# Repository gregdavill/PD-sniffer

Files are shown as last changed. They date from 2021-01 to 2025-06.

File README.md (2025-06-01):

# PD-Sniffer

This project is based off the Twinkie, a Google designed PD sniffer/analyser. [link](https://www.chromium.org/chromium-os/developer-library/guides/hardware-schematics/twinkie/)

Unfortunately the original designers of the Twinkie designed the hardware with laptop like specifications. As a result the design features a 6L PCB with stacked micro-vias. This makes it expensive to manufacture.

This re-design aims to keep the board specifications within the scope of PCB prototyping services, so it is easier for hobbyists and other open-source contributors to create and build a unit.

## Hardware versions

### v0.1 (FreshTwinkie)
The initial version aims to remain pin compatible with the original design, so firmware can be re-used. The main MCU is swapped from a BGA package to a QFN, and a 4L board construction is used. As a result many BGA devices are still used, as these were un-changed from the original design.

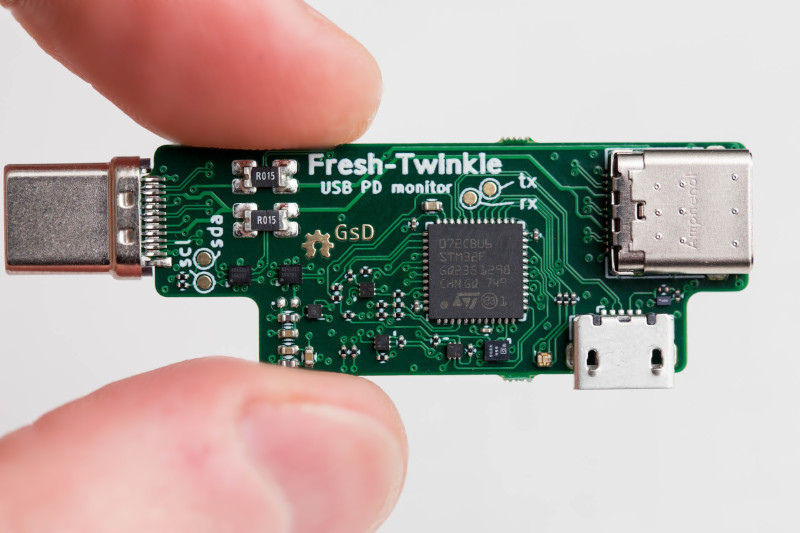
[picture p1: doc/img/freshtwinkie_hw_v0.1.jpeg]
fresh-twinkie-hw-v0.1


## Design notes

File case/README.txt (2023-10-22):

Parts list:
- 1x lower-case.stl
- 1x upper-case.stl
- 2x M2x8mm screw
- 2x M2 nut

This case has very fine features, mainly the latch, and works best when printed in plastics like PETG.
It was validated in transparent SUNLU PETG using a 0.4mm nozzle, sliced with variable layer height
(adaptive, factor 0.5) and 50% infill with PrusaSlicer 2.5.2. The LED shines brightly through the case
so no aperture for the LED was added.

SolveSpace exports triangle meshes that are a little broken, and the STL files included were repaired
through the Netfabb service.

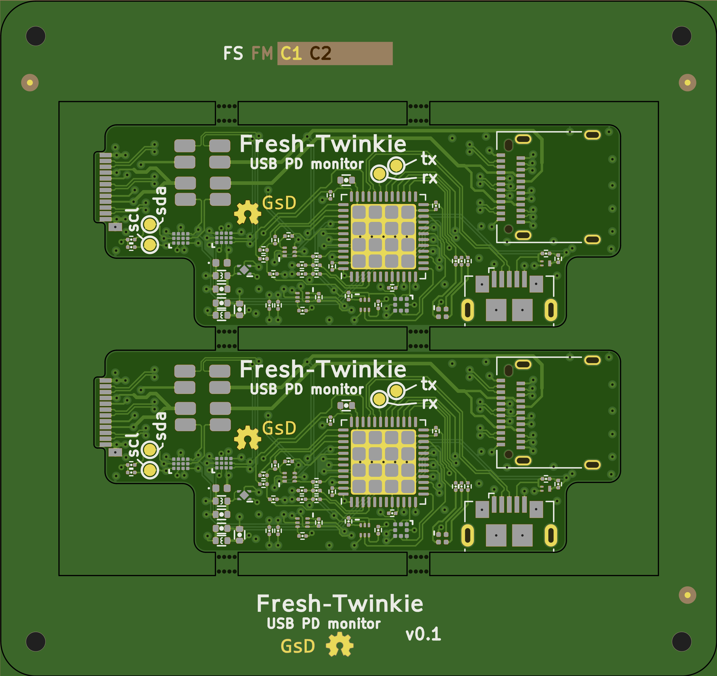
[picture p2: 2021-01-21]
hw/FreshTwinkie_v0.1_panel/plot/FreshTwinkie_v0.1_panel-Front.png

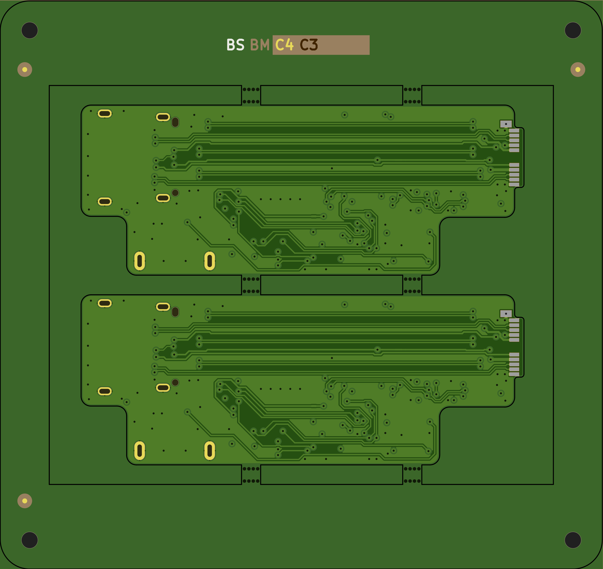
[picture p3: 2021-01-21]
hw/FreshTwinkie_v0.1_panel/plot/FreshTwinkie_v0.1_panel-Back.png

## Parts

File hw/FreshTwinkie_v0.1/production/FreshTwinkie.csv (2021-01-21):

Source: | /home/greg/projects/FreshTwinkie/hardware/FreshTwinkie_v0.1/FreshTwinkie.sch
Date: | Mon 05 Aug 2019 21:20:34 ACST
Tool: | Eeschema 5.1.2-f72e74a~84~ubuntu18.04.1
Generator: | /usr/share/kicad/plugins/bom_csv_grouped_by_value.py
Component Count: | 50
Individual Components:
Item | Qty | Reference(s) | Value | LibPart | Footprint | Datasheet | Mfg | PN
 |  | C1 | 1uF | Device:C | pkl_dipol:C_0402 | ~ | Samsung Electro-Mechanics | CL05A105MQ5NNNC
 |  | C2 | 100nF | Device:C | pkl_dipol:C_0201 | ~ | Samsung Electro-Mechanics | CL03A104KQ3NNNC
 |  | C3 | 100nF | Device:C | pkl_dipol:C_0201 | ~ | Samsung Electro-Mechanics | CL03A104KQ3NNNC
 |  | C4 | 4.7uF | Device:C | pkl_dipol:C_0402 | ~ | Samsung Electro-Mechanics | CL05A475MQ5NRNC
 |  | C5 | 10nF | Device:C | pkl_dipol:C_0201 | ~ | Samsung Electro-Mechanics | CL03B103KP3NNNC
 |  | C6 | 1uF | Device:C | pkl_dipol:C_0402 | ~ | Samsung Electro-Mechanics | CL05A105MQ5NNNC
 |  | C7 | 4.7uF | Device:C | pkl_dipol:C_0402 | ~ | Samsung Electro-Mechanics | CL05A475MQ5NRNC
 |  | C8 | 100nF | Device:C | pkl_dipol:C_0201 | ~ | Samsung Electro-Mechanics | CL03A104KQ3NNNC
 |  | D1 | 5.6V | Device:D_Zener_ALT | Diode_SMD:D_0402_1005Metric | ~
 |  | D2 | LED_ARGB | Device:LED_ARGB | gkl_led:0404LED_RGB | ~
 |  | FB1 | 600R | Device:Ferrite_Bead_Small | pkl_dipol:L_0402 | ~ | Murata Electronics North America | BLM15AG601SN1D
 |  | FB2 | 600R | Device:Ferrite_Bead_Small | pkl_dipol:L_0402 | ~ | Murata Electronics North America | BLM15AG601SN1D
 |  | J1 | USB_B_Micro | Connector:USB_B_Micro | Connector_USB:USB_Micro-B_GCT_USB3076-30-A | ~ | GCT | USB3076-30-A
 |  | J2 | USB_C_Receptacle | Connector:USB_C_Receptacle | Connector_USB:USB_C_Receptacle_Amphenol_12401610E4-2A | https://www.usb.org/sites/default/files/documents/usb_type-c.zip | Amphenol ICC (Commercial Products) | 12401610E4#2A
 |  | NT1 | Net-Tie_2 | Device:Net-Tie_2 | NetTie:NetTie-2_SMD_Pad0.5mm | ~
 |  | P1 | USB_C_Plug | Connector:USB_C_Plug | Connector_USB:USB_C_Plug_Molex_105444 | https://www.usb.org/sites/default/files/documents/usb_type-c.zip | Wurth Electronics Inc. | 632712000021
 |  | Q1 | PMDXB600UNE | gkl_mosfet:PMDXB600UNE | gkl_housings_qfn:DFN1010B-6 (SOT1216) | https://assets.nexperia.com/documents/data-sheet/PMDXB600UNE.pdf | Nexperia USA Inc. | PMDXB600UNEZ
 |  | Q2 | PMDXB600UNE | gkl_mosfet:PMDXB600UNE | gkl_housings_qfn:DFN1010B-6 (SOT1216) | https://assets.nexperia.com/documents/data-sheet/PMDXB600UNE.pdf | Nexperia USA Inc. | PMDXB600UNEZ
 |  | Q3 | PMDXB600UNE | gkl_mosfet:PMDXB600UNE | gkl_housings_qfn:DFN1010B-6 (SOT1216) | https://assets.nexperia.com/documents/data-sheet/PMDXB600UNE.pdf | Nexperia USA Inc. | PMDXB600UNEZ
 |  | Q4 | Q_NMOS_DGS | Device:Q_NMOS_DGS | gkl_housings_qfn:MOSFET_1.0x0.6mm | ~ | Texas Instruments | CSD13381F4
 |  | R1 | 0.015 | gkl_misc:4W_R | gkl_dipol:4W_R_1206 |  | Vishay Dale | WSK1206R0150FEA18
 |  | R2 | 0.015 | gkl_misc:4W_R | gkl_dipol:4W_R_1206 |  | Vishay Dale | WSK1206R0150FEA18
 |  | R3 | 381K | Device:R | gkl_dipol:R_0201 | ~ | Yageo | RC0201FR-07383KL
 |  | R4 | 381K | Device:R | gkl_dipol:R_0201 | ~ | Yageo | RC0201FR-07383KL
 |  | R5 | 4.75K | Device:R | gkl_dipol:R_0201 | ~ | Yageo | RC0201FR-074K75L
 |  | R6 | 4.75K | Device:R | gkl_dipol:R_0201 | ~ | Yageo | RC0201FR-074K75L
 |  | R7 | 1K | Device:R | gkl_dipol:R_0201 | ~ | Yageo | RC0201FR-071KL
 |  | R8 | 1K | Device:R | gkl_dipol:R_0201 | ~ | Yageo | RC0201FR-071KL
 |  | R9 | 12.1K | Device:R | gkl_dipol:R_0201 | ~ | Yageo | RC0201FR-0712K1L
 |  | R10 | 12.1K | Device:R | gkl_dipol:R_0201 | ~ | Yageo | RC0201FR-0712K1L
 |  | R11 | 5.11K | Device:R | gkl_dipol:R_0201 | ~ | Yageo | RC0201FR-075K11L
 |  | R12 | 5.11K | Device:R | gkl_dipol:R_0201 | ~ | Yageo | RC0201FR-075K11L
 |  | R13 | 35.7K | Device:R | gkl_dipol:R_0201 | ~ | Yageo | RC0201FR-0735K7L
 |  | R14 | 35.7K | Device:R | gkl_dipol:R_0201 | ~ | Yageo | RC0201FR-0735K7L
 |  | R15 | 200R | Device:R | gkl_dipol:R_0201 | ~ | Yageo | RC0201FR-07200RL
 |  | R16 | 100R | Device:R | gkl_dipol:R_0201 | ~ | Yageo | RC0201FR-07100RL
 |  | R17 | 200R | Device:R | gkl_dipol:R_0201 | ~ | Yageo | RC0201FR-07200RL
 |  | R18 | 100R | Device:R | gkl_dipol:R_0201 | ~ | Yageo | RC0201FR-07100RL
 |  | R19 | 51.1K | Device:R | gkl_dipol:R_0201 | ~ | Yageo | RC0201FR-0751k1L
 |  | R20 | 51.1K | Device:R | gkl_dipol:R_0201 | ~ | Yageo | RC0201FR-0751k1L
 |  | R21 | 576R | Device:R | gkl_dipol:R_0201 | ~ | Yageo | RC0201FR-07576RL
 |  | R22 | 2.12K | Device:R | gkl_dipol:R_0201 | ~ | Yageo | RC0201FR-072k1L
 |  | R23 | 604R | Device:R | gkl_dipol:R_0201 | ~ | Yageo | RC0201FR-07604RL
 |  | R24 | 2.12K | Device:R | gkl_dipol:R_0201 | ~ | Yageo | RC0201FR-072k1L
 |  | R25 | 806R | Device:R | gkl_dipol:R_0201 | ~ | Yageo | RC0201FR-07806RL
 |  | U1 | INA231 | gkl_sensor:INA231 | gkl_housings_bga:DSBGA-12_1.56x1.39mm_Layout3x4_P0.4mm |  | Texas Instruments | INA231AIYFFR
 |  | U2 | INA231 | gkl_sensor:INA231 | gkl_housings_bga:DSBGA-12_1.56x1.39mm_Layout3x4_P0.4mm |  | Texas Instruments | INA231AIYFFR
 |  | U3 | NCP167 | gkl_pmic:NCP167 | gkl_housings_son:X2SON_4_1.0x1.0mm | http://www.onsemi.com/pub/Collateral/NCP167-D.PDF | ON Semiconductor | NCP167BMX330TBG
 |  | U4 | AD8606ACB | gkl_misc:AD8606ACB | gkl_housings_bga:WLCSP-8 3X3_0.5 | https://www.analog.com/media/en/technical-documentation/data-sheets/AD8605_8606_8608.pdf | Analog Devices Inc. | AD8606ACBZ-REEL7
 |  | U5 | STM32F072CBUx | MCU_ST_STM32F0:STM32F072CBUx | Package_DFN_QFN:QFN-48-1EP_7x7mm_P0.5mm_EP5.6x5.6mm | http://www.st.com/st-web-ui/static/active/en/resource/technical/document/datasheet/DM00090510.pdf | STMicroelectronics | STM32F072CBU6
Collated Components:
Item | Qty | Reference(s) | Value | LibPart | Footprint | Datasheet | Mfg | PN
1 | 2 | C1, C6 | 1uF | Device:C | pkl_dipol:C_0402 | ~ | Samsung Electro-Mechanics | CL05A105MQ5NNNC
2 | 3 | C2, C3, C8 | 100nF | Device:C | pkl_dipol:C_0201 | ~ | Samsung Electro-Mechanics | CL03A104KQ3NNNC
3 | 2 | C4, C7 | 4.7uF | Device:C | pkl_dipol:C_0402 | ~ | Samsung Electro-Mechanics | CL05A475MQ5NRNC
4 | 1 | C5 | 10nF | Device:C | pkl_dipol:C_0201 | ~ | Samsung Electro-Mechanics | CL03B103KP3NNNC
5 | 1 | D1 | 5.6V | Device:D_Zener_ALT | Diode_SMD:D_0402_1005Metric | ~
6 | 1 | D2 | LED_ARGB | Device:LED_ARGB | gkl_led:0404LED_RGB | ~
7 | 2 | FB1, FB2 | 600R | Device:Ferrite_Bead_Small | pkl_dipol:L_0402 | ~ | Murata Electronics North America | BLM15AG601SN1D
8 | 1 | J1 | USB_B_Micro | Connector:USB_B_Micro | Connector_USB:USB_Micro-B_GCT_USB3076-30-A | ~ | GCT | USB3076-30-A
9 | 1 | J2 | USB_C_Receptacle | Connector:USB_C_Receptacle | Connector_USB:USB_C_Receptacle_Amphenol_12401610E4-2A | https://www.usb.org/sites/default/files/documents/usb_type-c.zip | Amphenol ICC (Commercial Products) | 12401610E4#2A
10 | 1 | NT1 | Net-Tie_2 | Device:Net-Tie_2 | NetTie:NetTie-2_SMD_Pad0.5mm | ~
11 | 1 | P1 | USB_C_Plug | Connector:USB_C_Plug | Connector_USB:USB_C_Plug_Molex_105444 | https://www.usb.org/sites/default/files/documents/usb_type-c.zip | Wurth Electronics Inc. | 632712000021
12 | 3 | Q1, Q2, Q3 | PMDXB600UNE | gkl_mosfet:PMDXB600UNE | gkl_housings_qfn:DFN1010B-6 (SOT1216) | https://assets.nexperia.com/documents/data-sheet/PMDXB600UNE.pdf | Nexperia USA Inc. | PMDXB600UNEZ
13 | 1 | Q4 | Q_NMOS_DGS | Device:Q_NMOS_DGS | gkl_housings_qfn:MOSFET_1.0x0.6mm | ~ | Texas Instruments | CSD13381F4
14 | 2 | R1, R2 | 0.015 | gkl_misc:4W_R | gkl_dipol:4W_R_1206 |  | Vishay Dale | WSK1206R0150FEA18
15 | 2 | R3, R4 | 381K | Device:R | gkl_dipol:R_0201 | ~ | Yageo | RC0201FR-07383KL
16 | 2 | R5, R6 | 4.75K | Device:R | gkl_dipol:R_0201 | ~ | Yageo | RC0201FR-074K75L
17 | 2 | R7, R8 | 1K | Device:R | gkl_dipol:R_0201 | ~ | Yageo | RC0201FR-071KL
18 | 2 | R9, R10 | 12.1K | Device:R | gkl_dipol:R_0201 | ~ | Yageo | RC0201FR-0712K1L
19 | 2 | R11, R12 | 5.11K | Device:R | gkl_dipol:R_0201 | ~ | Yageo | RC0201FR-075K11L
20 | 2 | R13, R14 | 35.7K | Device:R | gkl_dipol:R_0201 | ~ | Yageo | RC0201FR-0735K7L
21 | 2 | R15, R17 | 200R | Device:R | gkl_dipol:R_0201 | ~ | Yageo | RC0201FR-07200RL
22 | 2 | R16, R18 | 100R | Device:R | gkl_dipol:R_0201 | ~ | Yageo | RC0201FR-07100RL
23 | 2 | R19, R20 | 51.1K | Device:R | gkl_dipol:R_0201 | ~ | Yageo | RC0201FR-0751k1L
24 | 1 | R21 | 576R | Device:R | gkl_dipol:R_0201 | ~ | Yageo | RC0201FR-07576RL
25 | 2 | R22, R24 | 2.12K | Device:R | gkl_dipol:R_0201 | ~ | Yageo | RC0201FR-072k1L
26 | 1 | R23 | 604R | Device:R | gkl_dipol:R_0201 | ~ | Yageo | RC0201FR-07604RL
27 | 1 | R25 | 806R | Device:R | gkl_dipol:R_0201 | ~ | Yageo | RC0201FR-07806RL
28 | 2 | U1, U2 | INA231 | gkl_sensor:INA231 | gkl_housings_bga:DSBGA-12_1.56x1.39mm_Layout3x4_P0.4mm |  | Texas Instruments | INA231AIYFFR
29 | 1 | U3 | NCP167 | gkl_pmic:NCP167 | gkl_housings_son:X2SON_4_1.0x1.0mm | http://www.onsemi.com/pub/Collateral/NCP167-D.PDF | ON Semiconductor | NCP167BMX330TBG
30 | 1 | U4 | AD8606ACB | gkl_misc:AD8606ACB | gkl_housings_bga:WLCSP-8 3X3_0.5 | https://www.analog.com/media/en/technical-documentation/data-sheets/AD8605_8606_8608.pdf | Analog Devices Inc. | AD8606ACBZ-REEL7
31 | 1 | U5 | STM32F072CBUx | MCU_ST_STM32F0:STM32F072CBUx | Package_DFN_QFN:QFN-48-1EP_7x7mm_P0.5mm_EP5.6x5.6mm | http://www.st.com/st-web-ui/static/active/en/resource/technical/document/datasheet/DM00090510.pdf | STMicroelectronics | STM32F072CBU6

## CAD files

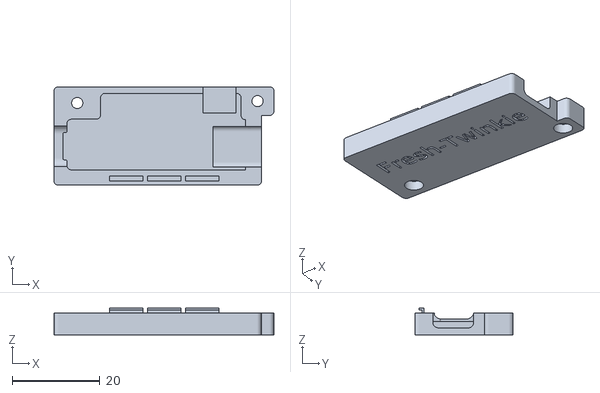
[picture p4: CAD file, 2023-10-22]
case/upper-case.stl
50.1 x 22.5 x 6.09

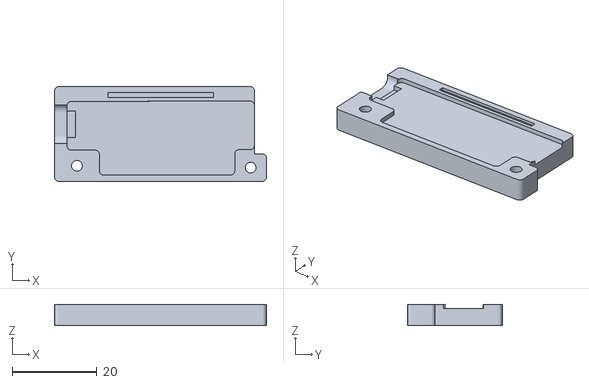
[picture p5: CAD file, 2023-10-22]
case/lower-case.stl
50.1 x 22.4 x 5.00

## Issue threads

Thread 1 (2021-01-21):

[v0.1] ID pin based boot scheme does not work

whitequark, 2021-01-21:
It seems that the USB_B_VBUS net (as shown on original Twinkie schematic) is not connected on Fresh-Twinkie, making it impossible (AFAIK) to boot without cutting the trace. The workaround is to cut the BOOT trace and connect it to Vcc.

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

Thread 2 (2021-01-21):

[v0.1] Simplify bootloader entry

whitequark, 2021-01-21:
The ID pin based bootloader entry scheme is highly inconvenient and requires using an illegal USB cable. Most end users will probably only need to enter the ROM bootloader once, so a test point is fine. I can see developers entering the ROM bootloader more often, so a button in parallel with a test point (which could be DNP) would be quite nice, especially on a high density board like this.

whitequark, 2021-02-09:
> if you are planning to re-use part of the original firmware, it does include a 'dfu' command over the USB-serial console to switch it back to bootloader mode

Yeah and the command is broken...

whitequark, 2021-02-09:
I think the command might actually be broken because of #1? I don't know how exactly it works, but the symptoms are that I can enter DFU mode but trying to flash anything instantly resets the device. I haven't tried it with the workaround for #1 yet.

whitequark, 2021-02-09:
Sorry, I understand I probably sound quite hostile, that's not my intention. I've just had a lot of trouble with both USB PD *and* USB PD debuggers and after a few months of it that gets frustrating.

dnschneid, 2021-02-16:
Buttons are nice as long as you can access them when the unit is enclosed in its enclosure and including it doesn't cause the enclosure to be larger than absolutely necessary (since any increase in case size results in more torque on the Type-C plug).

I think the USB-ID trick is especially convenient for us since we've been using the trick across multiple internal boards for years, so our devs tend to have them on-hand.  Never had an issue with it (although it's best to plug in the micro-B side before the usb-A side).

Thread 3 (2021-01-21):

[v0.1] Use more DIY friendly packages

whitequark, 2021-01-21:
All of the components on the board are available in larger/coarser packages than the v0.1 design. Switching to 0603 min passives and replacing BGA/CSP packages with QFN/DFN would make the board easier to assemble and examine while not making it much larger.

FalconFour, 2024-11-12:
Aye... I wanted to build this but PCBway barfed it back out saying the clearance is too small (minimum 0.1mm, but wider is much cheaper). Board seems to have 0.08mm. Would much prefer a larger board that omits USB/Thunderbolt passthrough, something simple that just lets me intercept USB-PD data, something just in my personal toolkit to help observe the invisible (and sometimes problematic) things that devices do...

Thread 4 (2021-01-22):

RFC: Improving alternate modes for captive cable compatibility.

hardkrash, 2021-01-22:
The design currently has a single routing of USB 2.0 pairs.  This can cause some adapters with alternate modes to fail to operate properly.  Captive plug alternate modes can remap the alternate USB pair B6+B7 for its own purposes.  reference Figure E2 in section e.2.1 of the document [USB Type-C Spec R2.0 - August 2019.pdf](https://usb.org/document-library/usb-type-cr-cable-and-connector-specification-revision-20)

I propose mapping the USB 2.0 lines as 2x pairs for each A6+A7 and B7+B7.

The con of this is that a stub could be created with a device receptacle that has shorted the A6 to B6 and A7 to B7.
This could be solved with resistor stuffing to allow the current configuration, and a pass through for those uses that require passthrough.

Future FW could alleviate this with a software controlled USB 2.0 muxing solution.

I'm unsure if the stub with the passive approach would cause much of an issue...
I have successfully done stub monitoring with short 200mm cables to a Total Phase 480mbps beagle.
The core difference here is that the stub would be floating with

gregdavill, 2021-01-22:
This seems like a good idea.

whitequark, 2021-01-23:
Excellent catch @hardkrash! I agree this is a good idea.

dnschneid, 2021-02-09:
I've found that stubs of an inch or two can break high-speed USB.  Muxing would be great, though.

whitequark, 2021-02-09:
I think we can do muxing, though I think we should at least extract the firmware and make it easy to build as a part of this repo before committing to that. (I believe right now it can only be built out of a ChromeOS tree, which isn't something I would like to offer for general use.)

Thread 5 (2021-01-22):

[v0.1] Form Factor

gregdavill, 2021-01-22:
The current design features an upstream Type-C plug and downstream Type-C socket.
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

This is designed to plug directly into a host, but the Type-C paddle mounted connectors mean we're forced to use a 0.8mm PCB, and the overall design feels a bit flimsy.
Potentially a 3d printed case might help?

Would it be possible to use two Type-C sockets, and then maybe house the device in a small extruded aluminum case as shown?
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

whitequark, 2021-01-23:
> This is designed to plug directly into a host, but the Type-C paddle mounted connectors mean we're forced to use a 0.8mm PCB, and the overall design feels a bit flimsy.
> Potentially a 3d printed case might help?

These are exactly my thoughts--I think I was going to file a bug but forgot.

> Would it be possible to use two Type-C sockets, and then maybe house the device in a small extruded aluminum case as shown?

Unfortunately, I don't think two sockets will work. If you are using something that requires e-marked cables, I think (based on my understanding of the PD spec) that will just garble the communication since there's only SOP' and SOP'' to address the markers. Also, if you are using something like Thunderbolt, two cables plus the PD sniffer PCB might exhaust the entire link budget. I am very interested in using it for both of these applications.

The latter reason also excludes e.g. having two connectors with a mux picking between them, since you cannot pick a mux that handles every conceivable altmode. The board has to stay passive and functional with only a single cable involved, or it will lose a lot of its usefulness.

I think a sturdy case, 3d printed or not, is the way to go. I expect some boards will break during use, but... it's not a complex or expensive board (now that we aren't using Google's absurd design rules) so it's not a huge loss. In any case, plugging *suspicious* type-C stuff into a type-C debugger directly electrically interfacing the lines is inherently hazardous. We don't even have protection from having 20V on the CC lines; anyone using this sniffer ought to buy them in pairs!

hardkrash, 2021-01-23:
If you wanted to move away from a PCB mount plug then the other option is to use a captive cable.
It appears that this might be the correct cable, but I cannot tell as their data sheets seem to not match well with their product's pages.

https://www.wit-area.com/20v-5A-100w-USB-C-cable-63.html
If these are not exactly what you need they might have a different version that I couldn't find exact details from their data sheets.  It seems pretty hard to find these online and listed.

If you wanted two receptacles then you would want to get a cable like this one from Acroname.
https://acroname.com/store/c38-usbc-uoc

This is the problem that Acroname had to solve for their passive USB-C switch.
https://acroname.com/store/s85-rdvr-usbcsw?sku=S85-PASS-USBCSW

With all this I agree with @whitequark that the plug with an enclosure would work reasonably well.  Especially with a connector that has some mechanical stability designed in.  e.g. the JAE DX07P024MJ1R1500
this connector can get some metal attached to the shell and get firmer mounting to the PCB or enclosure.

Note: it is super easy to break un-reinforced type-c plugs off of boards.  The pads alone don't have enough adhesion to retain the connectors.

whitequark, 2021-01-23:
> If you wanted to move away from a PCB mount plug then the other option is to use a captive cable.

This seems like it would be very hostile to DIY. Is that microcoax on the cable you linked? I think that would be a problem for many people, myself included.

> If you wanted two receptacles then you would want to get a cable like this one from Acroname.

This is more reasonable but I think it's still kinda hostile to DIY; not only you need to get a custom device (which we can maybe get to be easily orderable through e.g. JLCPCB) but now you also need a custom cable with very few suppliers which is also not easy to find a second source for.

(Thanks for bringing it to my attention though!)

> Note: it is super easy to break un-reinforced type-c plugs off of boards. The pads alone don't have enough adhesion to retain the connectors.

That's how I felt about it, too. Guess I'm going to be even more careful now that you've confirmed it!

hardkrash, 2021-01-24:
There are different options for board edge midplane USB-C plugs,  The [DX07P024MJ1](https://www.jae.com/en/connectors/series/detail/id=86993&standard_code=S0010) from JAE has extra mechanical strength by having the shell extend back to get better leverage and mechanical durability as the connectors pins are now not the mounting point.

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

Generated with a SnapEDA footprint modified to work with the USB-Plug footprint.
Steps to reproduce:
- Download [DX07P024MJ1](https://www.snapeda.com/parts/DX07P024MJ1R1500/JAE%20Electronics/view-part/)
- Add to library
- Edit all shield pads to signal S1
- Add step file to footprint with z offset of -0.05mm
- Replace existing plug footprint with JAE footprint.
- A touch of layout and outline work.

I'm on Nightly and don't know KiCad 5, so not sure about submitting a branch with the modifications.

hardkrash, 2021-01-24:
> > If you wanted to move away from a PCB mount plug then the other option is to use a captive cable.
>
> This seems like it would be very hostile to DIY. Is that microcoax on the cable you linked? I think that would be a problem for many people, myself included.

I would expect the cable to be shielded twisted pair (STP).  I agree that terminating shielded twisted pair is not DIY friendly, it would require good magnification.  Terminating micro-coax is at the high end of difficult DIY.

whitequark, 2021-01-24:
To be explicit about my goals, I want to have a device that would reduce USB-related frustration, so I'm strongly biased towards solutions that are, perhaps, suboptimal, but do not require specialized skills, or even skills most people could probably acquire quickly but are afraid of (like BGA soldering for example). I think there is a space for a more complex PD debugger that is also more capable, but I'd really like to fill a baseline need first.

gregdavill, 2021-01-24:
> ... plugging _suspicious_ type-C stuff into a type-C debugger directly electrically interfacing the lines is inherently hazardous. We don't even have protection from having 20V on the CC lines; anyone using this sniffer ought to buy them in pairs!

Is there an easy way to add 20V protection? I notice this is a common feature on some of the integrated PD controllers.
I guess at a minimum we should try to ensure a 20V fault can't propagate back through the USB 2.0 interface.

whitequark, 2021-01-24:
> Is there an easy way to add 20V protection?

Maybe pass FETs? Paging @electronic_eel

whitequark, 2021-01-24:
> Is there an easy way to add 20V protection?

Maybe pass FETs? Paging @electroniceel

gregdavill, 2021-01-24:
A very quick search shows some integrated solutions, that at-least cover CC/SBU pins.

NX20P0407, or TPD8S300

whitequark, 2021-01-24:
Oh neat, I knew about TPD4 but not TPD8

hardkrash, 2021-01-25:
24 pin Type-C connectors sorted for my opinion of easiest soldering:

Plugs:
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
electroniceel, 2021-01-25:
> > Is there an easy way to add 20V protection?
>
> Maybe pass FETs? Paging @electroniceel

For the CC lines you could do it like I have planned for my Glasgow protection addon: https://github.com/electroniceel/io-protection-notes
Unfortunately I haven't continued to work on this since I started doing other Glasgow-related work. So this is more in the state of a design concept and not a fully tried and tested schematics you can just copy and it works.

electroniceel, 2021-01-25:
> If something more fancy is done for the USB 2.0 data lines requiring protection. Then 20V protection could be integrated with a [TS5USBC41](https://www.ti.com/product/TS5USBC41) Unfortunately it is a DSBGA package. :-/
>
> The NXP part above also has a sibling part for USB 2.0 protection [NX20P0408](https://www.nxp.com/products/power-management/load-switches/single-chip-usb-data-lines-protection-solution:NX20P0408). Unfortunately it is also WLCSP12.

Protecting D+/D- from >20 V is the really tricky part and these seem to do it. Nice. I didn't know there was an IC that could do it.

Since these are really small, we could consider adding them to the regular Glasgow ports. They don't protect from negative voltages and don't cover Vio, but they'd still make regular Glasgow much more resilient.

Only real downside are the packages.

I will order some samples and play with them a bit.

hardkrash, 2021-01-28:
I bought some Type-C plug breakout boards with the JAE DX07P024MJ1, they are much more stable than other SMT midmount options.

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

I would use this in my lab without a case.

dnschneid, 2021-02-09:
Some thoughts:

* Twinkie is already 20V tolerant on CC as long as you are only sniffing (Q1 provides that protection).  If you start transmitting into 20V, you'll probably blow the low side of Q2/Q3.
* The Google design is stupid expensive because we only had access to really weak prototype plug connectors and wanted to minimize the torque on that connector, so we basically crammed everything as tight as we could (Twinkie was made during early development of the USB-C spec).  This is actually well beyond the tech most of our Chromebooks are built to.
* Keeping one side of the Type-C plug narrow is useful to ensure you can fit two next to each other on a hub or other minimally-spaced multi-port machine.  This makes the panel mount connector less attractive, as you've noted.
* The mounting side lobes on some plug connectors are good for pull resistance, but still not great for the up-and-down torque you get from having essentially a 2-inch long connector.  The only way to make that better other than doing radical things is to find a connector that works with a thicker board...
* Twinkie had a molded plastic case in two halves, glued together -- this did not provide adequate strain relief on the plug.  3D printed might work if you can keep the plug end as a single piece, with tight tolerances on the plug hole.  Maybe a bucket-style case you can slide the freshness into before sealing it off at the end...just like a real Twinkie :)
* If you want to go really robust without needing a case, Antenk has some vertical-mount SMT connectors, both plug and receptacle, that are low-profile.  I've played with them a little for low-speed stuff; they seem alright and let you make a much thicker board.  I haven't tested them for SI.  You can put the connectors just above each other vertically, on opposite sides of the board, and have very short traces, with the sniffing sections flagging up vertically.  It'll be a bizarre form-factor but might work well.  Main downside is that those connectors are pretty much impossible to hand-solder.  U3.1MS04-S-L-P-G0-D for the plug and U3.1FM02-S-L-P-G0-D for the receptacle.

gregdavill, 2021-02-09:
Thanks for these insights @dnschneid!

dop3j0e, 2021-02-17:
FWIW, I solved this in an unconventional way in the Twonkie: I'm using vertical-mount connectors and using them as straddle mounts (or rather, touch-the-board-edge mounts). This requires some minor physical modification to the connectors (removing some mounting features that are in the way and slightly bending the pins for better contact) but it worked like a charm on two specimens so far, much easier to get right than I expected, and since I solder the shell to the PCB surrounding the connector it's also rock solid mechanically.

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

I was a little afraid that the little stubs created by the pins would cause problems on the high speed links but both boards I built so far support TB3 20Gb/s links just fine.

Of course this is not suitable for automated assembly but it works pretty well for DIY.

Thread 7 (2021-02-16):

[v0.1] Eliminate Q2 and Q3

dnschneid, 2021-02-16:
This requires minor code changes, but sort of similar to [this design](https://chromium.googlesource.com/chromiumos/platform/ec/+/refs/heads/stabilize-8714.B/board/glados_pd/dualtcpc.md), you can eliminate the Q2 and Q3 double FETs and drive the resistors directly from the STM32.  Resistors need to be reduced in value to compensate for the STM32's weaker GPIOs (probably 75 ohms on the low end and 150 ohms on the high end).

Code needs to be changed to make CC1_TX_EN become CC1_TX_EN_ODL -- that is, when transmitting, drive low on the GPIO, and when not transmitting, leave it high-impedance.

This is divergent from the Twinkie firmware, but only matters in the device emulation mode case, so at least the sniffing firmware can be used unchanged.  It eliminates 4 FETs, which is of course great for hand assembly.

I would of course recommend prototyping this on existing units and ensuring that the voltages and duty cycle turn out right.

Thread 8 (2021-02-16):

[v0.1] BOM simplification

dnschneid, 2021-02-16:
Might be nice to reduce the unique BOM items for the sake of making it easy for DIYers to prep materials.

None of these should have functional impact:

* R22 and R24 could be 1K (equal to R7); although check the datasheets to ensure the I2C current isn't too high.
* R3, R4, R19 and R20 could be...pretty much anything.  35.7K seems like a good choice (matches R13/R14)
* Unless you're trying for accurate color reproduction, you can make R21 and R23 the same value (they're within 5% anyway), probably 590 ohms.
* Depending on whether or not you value BOM count over complexity, R15 could be split into two resistors in series, equal to R16 (same with R17 vs R18)
* Similarly, R25 could be a 1K (R7/R8) and a 4.75K (R5/R6) in parallel.

Fun fact: some of the weird resistor values (51.1k on the ID pin) were due to BOM reductions with respect to an early version of the Type-C spec that had different CC resistor values.

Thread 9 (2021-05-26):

EPR support

dnschneid, 2021-05-26:
The INA231 only goes up to 28V (and will pop above 30V), but the new EPR spec has voltages up to 48V.

At the moment, the Chromium Twinkie design doesn't have a replacement, but the FreshTwinkie should consider alternative parts.  [They all seem to be much larger, though](https://www.ti.com/amplifier-circuit/current-sense/power-current-monitors/products.html#p726max=80;85&p929=I2C).

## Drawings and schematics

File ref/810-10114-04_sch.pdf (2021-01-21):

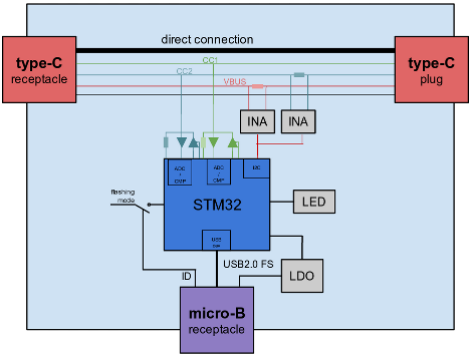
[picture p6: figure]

Thu Jan 8 13:33:56 2015 | 1 OF 2

# Twinkie USB PD debugger

# SCH: 810-10114-04 ASSY:803-10114-04 PCB: 180-10114-04

1 | TABLE OF CONTENTS
2 | TWINKIE
twinkie | 810-10114-04 | 0.00

# TABLE OF CONTENTS

SHEET NO. | SHEET NAME

## TABLE OF CONTENTS

DESIGN:

TITLE:

PAGE

13

DOC NUMBER:

FLAT:
16

17

17

9

L

K | K
J | J

H

G

F

E | E
D | D
C | C
B | B

A

L

G

F

1 | 2 | 3 | 5 | 6 | 7 | 8 | 10 | 11 | 12 | 13 | 14 | 16
4 | 5 | 6 | 7 | 8 | 9

4

2

3 | 14 | 15

PAGE:

REV:
MODIFIED:
1 | 10 | 11

A

H

12

THESE MATERIALS (INCLUDING ALL TEXT, SOFTWARE, CODE, DISPLAYS, ARTWORK, AND IMAGES) ARE LICENSED UNDER A CREATIVE COMMONS ATTRIBUTION 2.5 LICENSE.

15

### B=3.0MA@3.2VF

### G=3.0MA@3.3VF

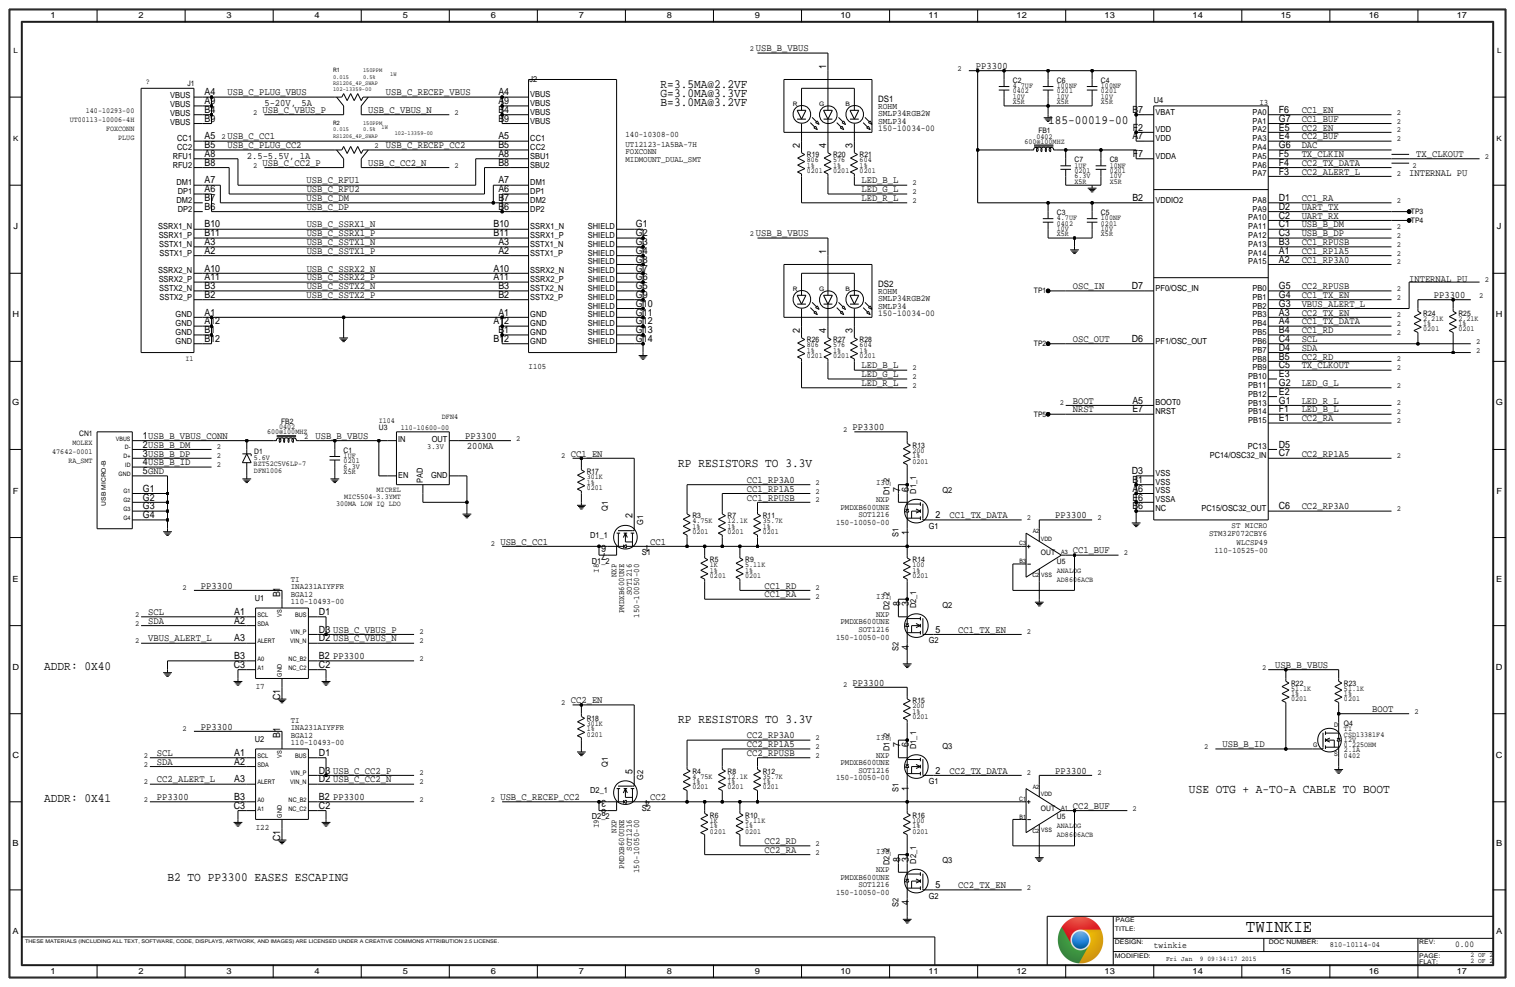
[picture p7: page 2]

B11 USB_C_SSRX1_P B11 | G2
A3 USB_C_SSTX1_N A3 | G3
A2 USB_C_SSTX1_P A2 | G4
A10 USB_C_SSRX2_N A10 | G8

B1 | | B1
B12 | B12

USB_B_ID
USE OTG + A-TO-A CABLE TO BOOT

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

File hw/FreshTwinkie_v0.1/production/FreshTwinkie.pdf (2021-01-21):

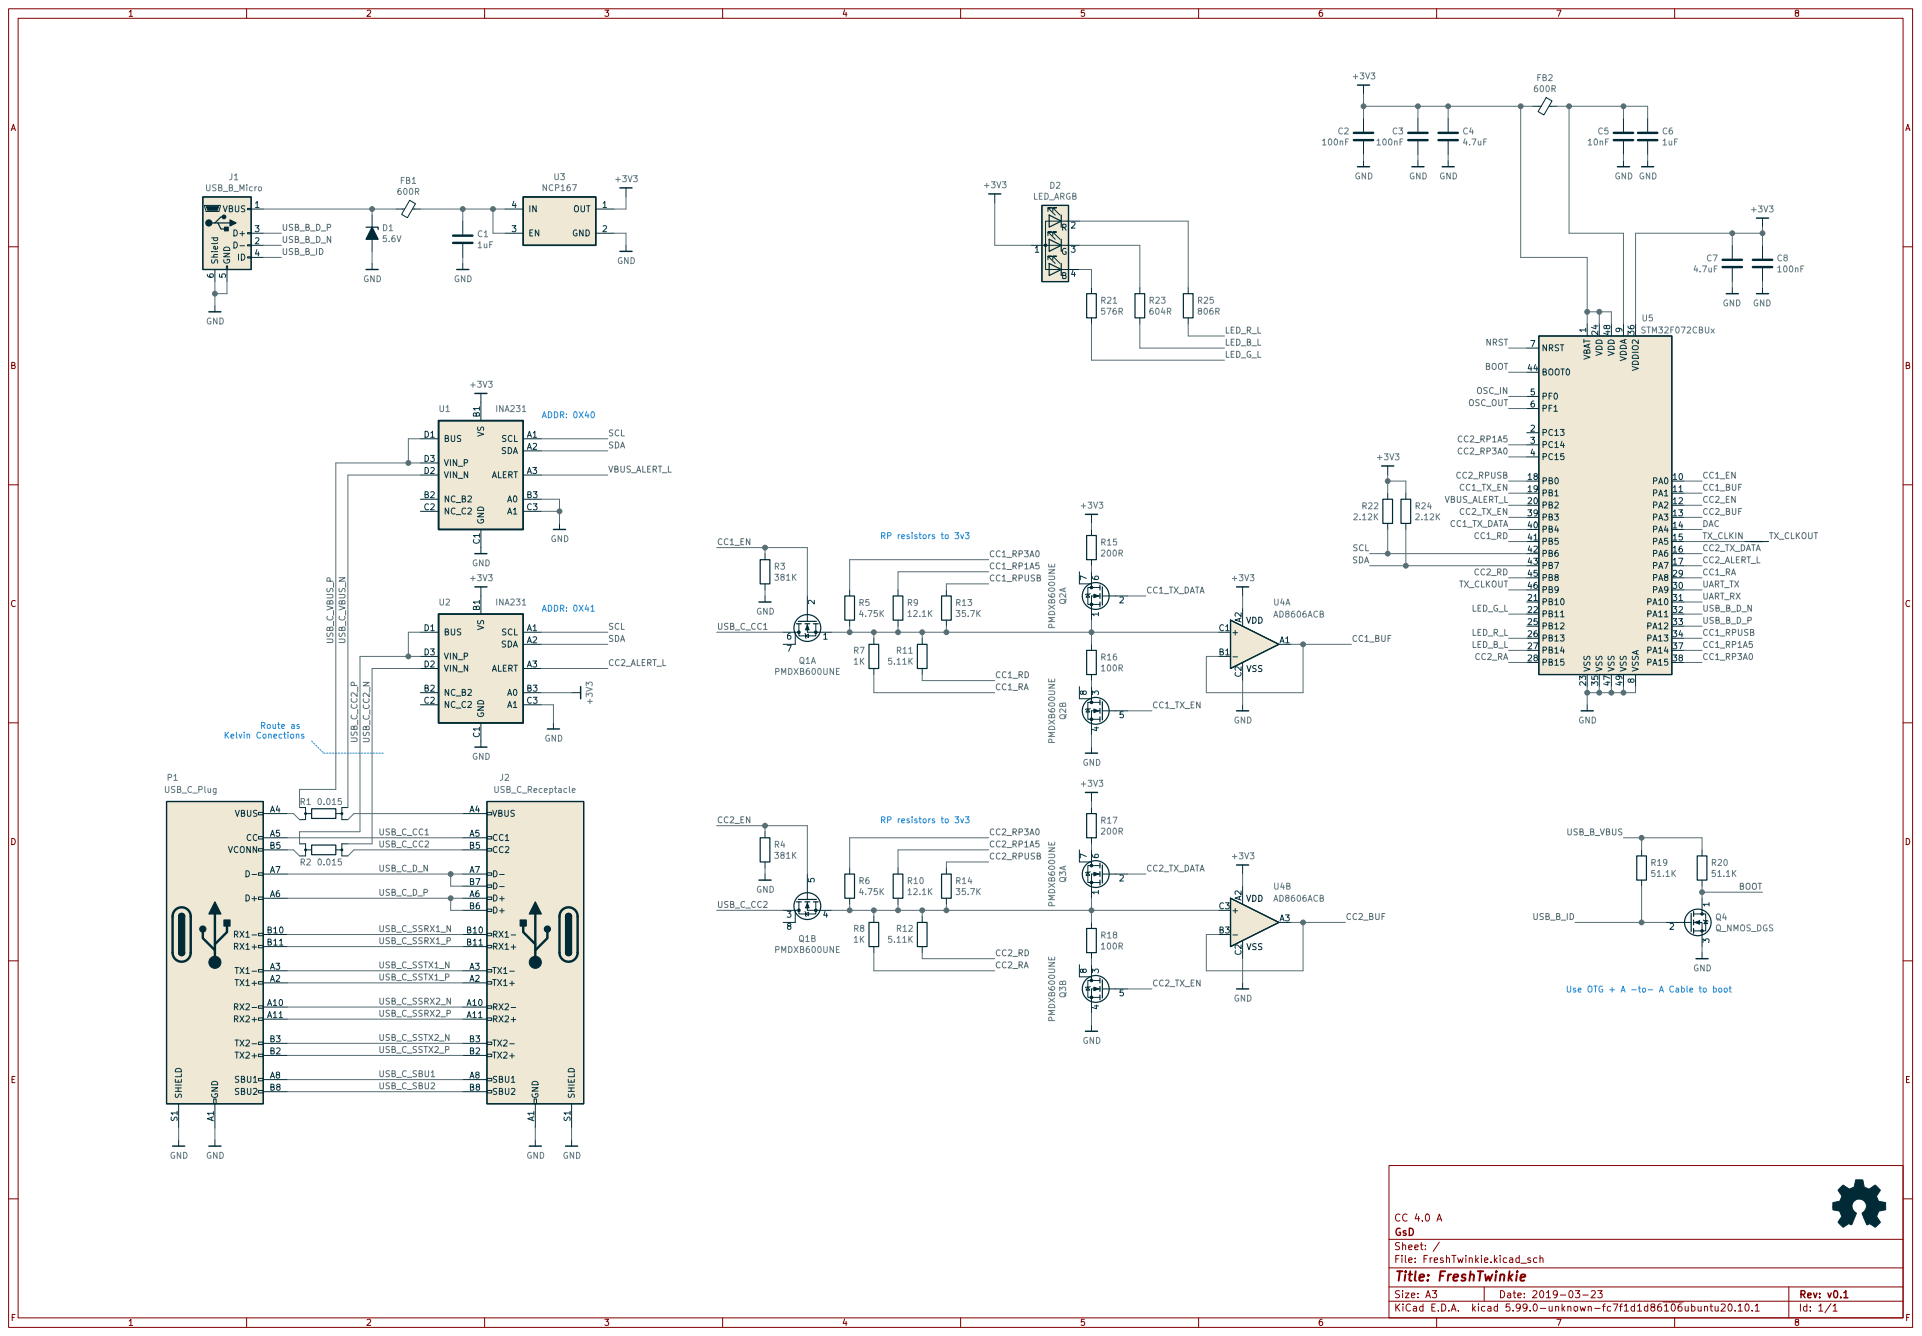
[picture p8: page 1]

9 U5STM32F072CBUx SCL A1 SDA A2 ALERT A3 VS B1 NC_B2 B2 A0 B3 GND C1 NC_C2 C2 A1 C3 BUS D1 VIN_N D2 VIN_P D3 U2 INA231 +3V3 R18

File: FreshTwinkie.kicad_sch Sheet: / GsD

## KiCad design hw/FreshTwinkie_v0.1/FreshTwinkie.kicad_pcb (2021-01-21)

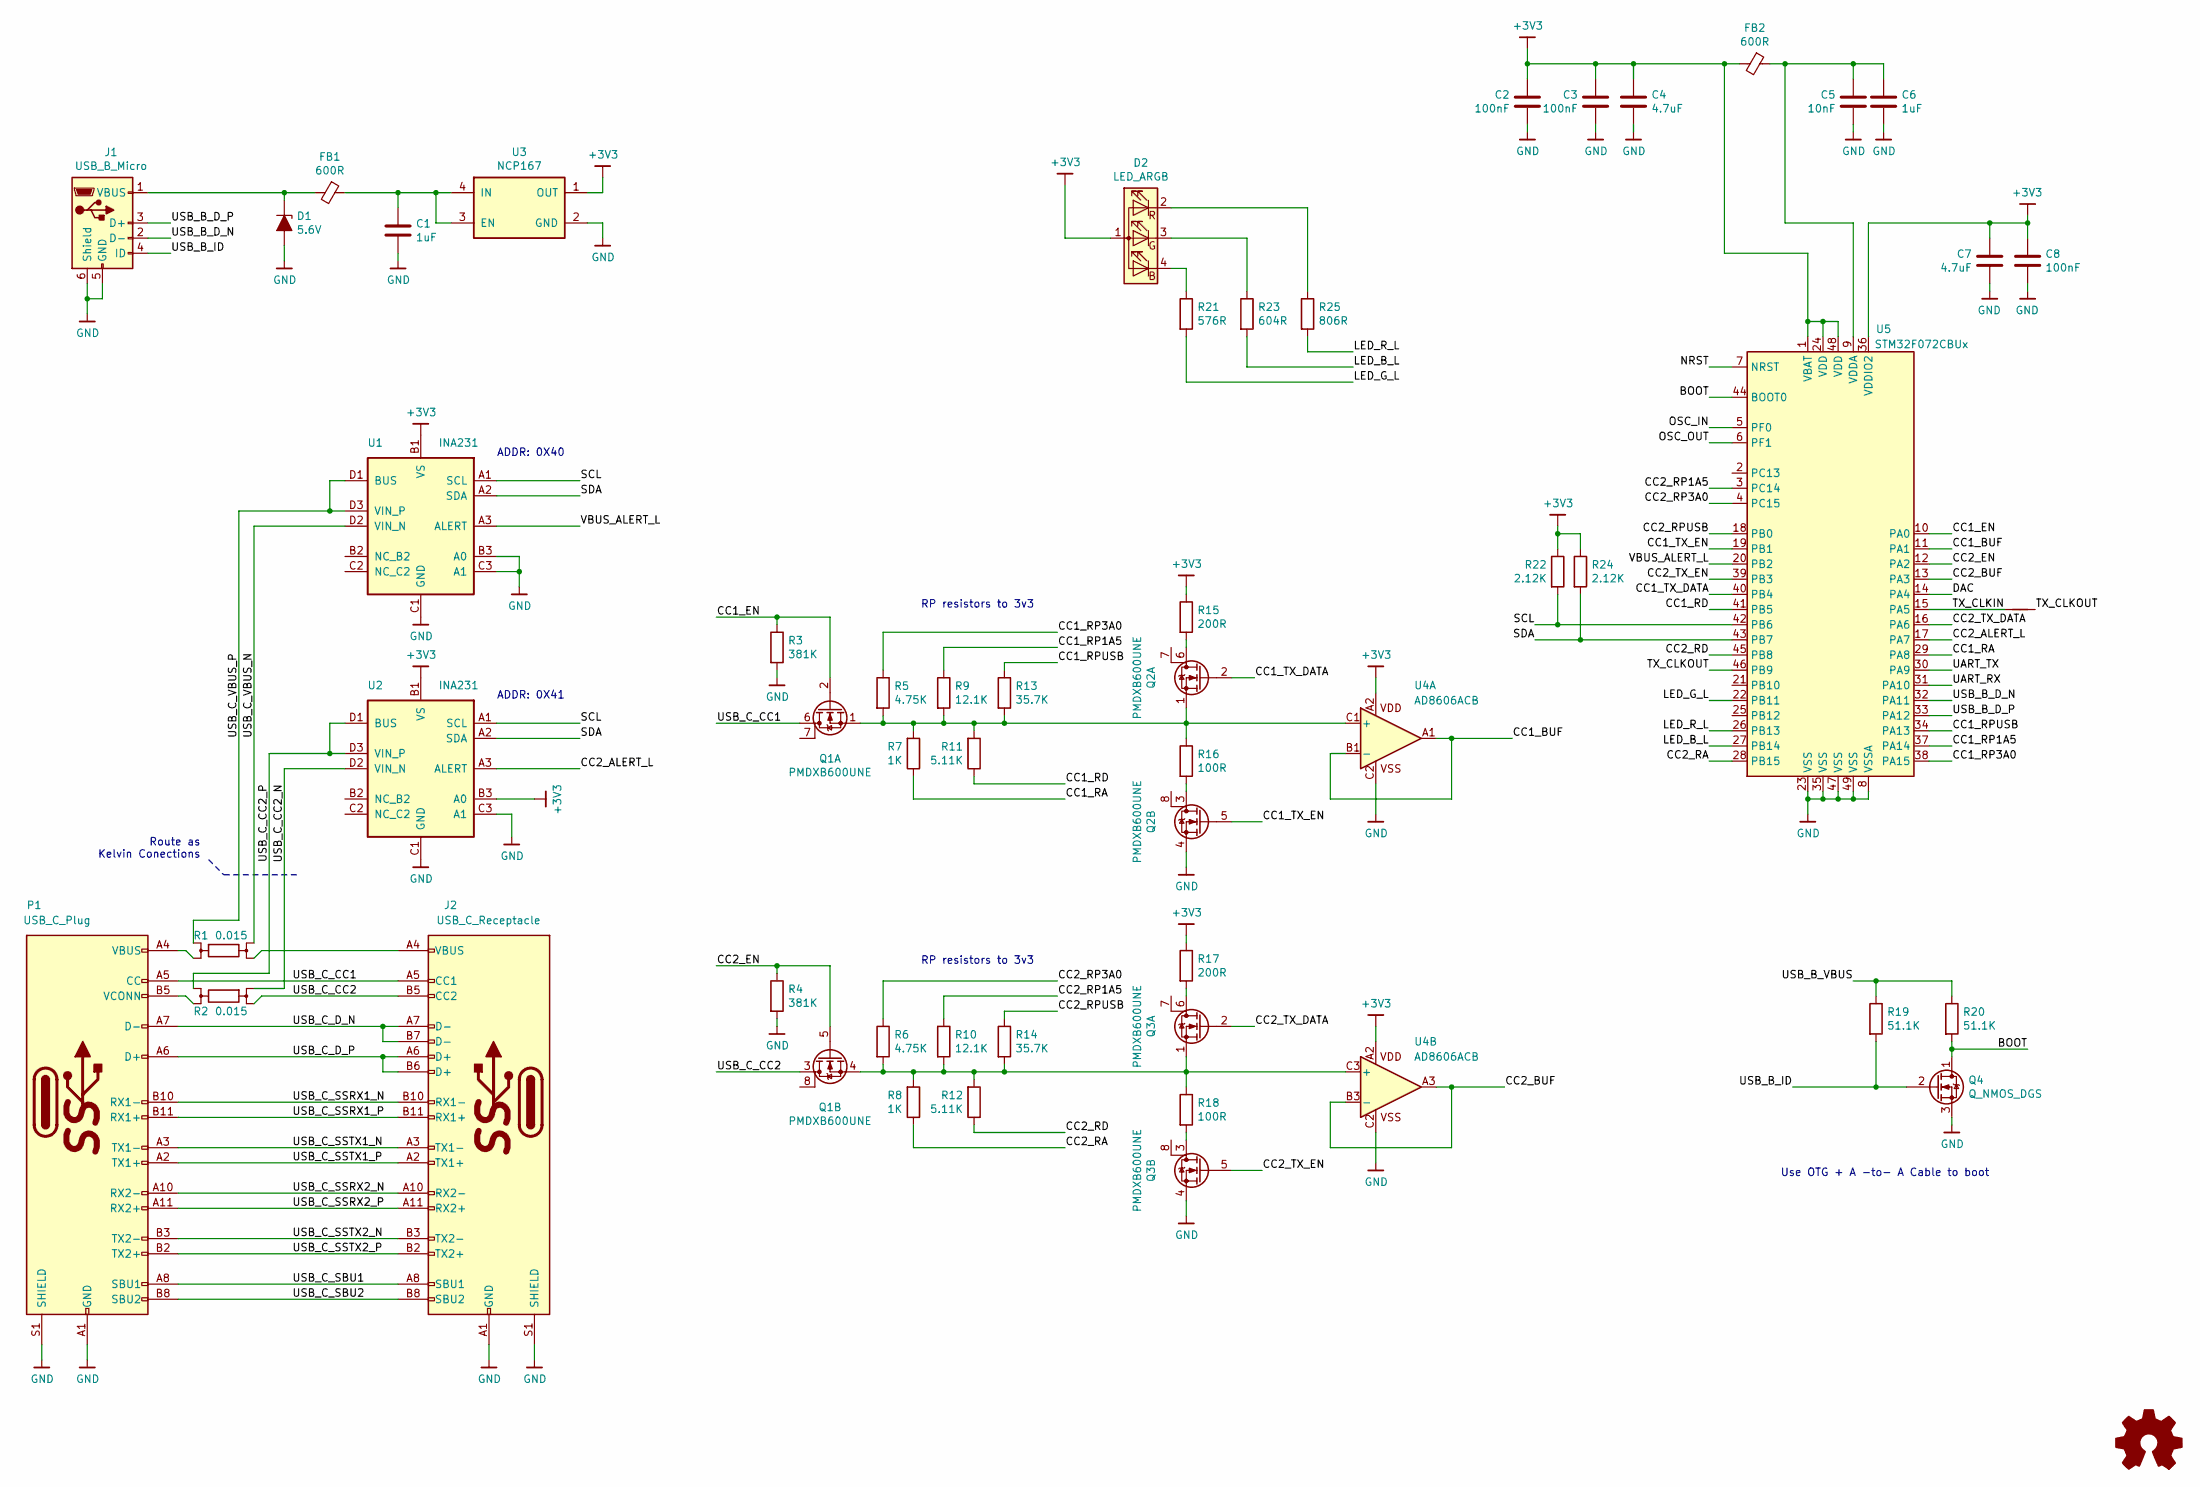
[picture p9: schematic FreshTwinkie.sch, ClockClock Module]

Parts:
C1, C6: 1uF; C_0402
C2, C3, C8: 100nF; C_0201
C4, C7: 4.7uF; C_0402
C5: 10nF; C_0201
D1: 5.6V; D_0402_1005Metric
D2: LED_ARGB; 0404LED_RGB
FB1, FB2: 600R; L_0402
J1: USB_B_Micro; USB_Micro-B_GCT_USB3076-30-A
J2: USB_C_Receptacle; USB_C_Receptacle_Amphenol_12401610E4-2A
NT1: Net-Tie_2; NetTie-2_SMD_Pad0.5mm
P1: USB_C_Plug; USB_C_Plug_Molex_105444
Q1, Q2, Q3: PMDXB600UNE; DFN1010B-6 (SOT1216)
Q4: Q_NMOS_DGS; MOSFET_1.0x0.6mm
R1, R2: 0.015; 4W_R_1206
R3, R4: 381K; R_0201
R5, R6: 4.75K; R_0201
R7, R8: 1K; R_0201
R9, R10: 12.1K; R_0201
R11, R12: 5.11K; R_0201
R13, R14: 35.7K; R_0201
R15, R17: 200R; R_0201
R16, R18: 100R; R_0201
R19, R20: 51.1K; R_0201
R21: 576R; R_0201
R22, R24: 2.12K; R_0201
R23: 604R; R_0201
R25: 806R; R_0201
U1, U2: INA231; DSBGA-12_1.56x1.39mm_Layout3x4_P0.4mm
U3: NCP167; X2SON_4_1.0x1.0mm
U4: AD8606ACB; WLCSP-8 3X3_0.5
U5: STM32F072CBUx; QFN-48-1EP_7x7mm_P0.5mm_EP5.6x5.6mm

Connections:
+3V3: C2.1, C3.1, C4.1, C7.1, C8.1, D2.1 (A), FB2.2, R15.1, R17.1, R22.1, R24.1, U1.B1 (VS), U2.B1 (VS), U2.B3 (A0), U3.1 (OUT), U4.A2, U5.1 (VBAT), U5.24 (VDD), U5.36 (VDDIO2), U5.48 (VDD)
/BOOT: Q4.1 (D), R20.2, U5.44 (BOOT0)
/CC1_BUF: U4.A1, U4.B1 (-), U5.11 (PA1)
/CC1_EN: Q1.2 (G), R3.1, U5.10 (PA0)
/CC1_RA: R7.1, U5.29 (PA8)
/CC1_RD: R11.1, U5.41 (PB5)
/CC1_RP1A5: R9.1, U5.37 (PA14)
/CC1_RP3A0: R5.1, U5.38 (PA15)
/CC1_RPUSB: R13.1, U5.34 (PA13)
/CC1_TX_DATA: Q2.2 (G), U5.40 (PB4)
/CC1_TX_EN: Q2.5 (G), U5.19 (PB1)
/CC2_ALERT_L: U2.A3 (ALERT), U5.17 (PA7)
/CC2_BUF: U4.A3, U4.B3 (-), U5.13 (PA3)
/CC2_EN: Q1.5 (G), R4.1, U5.12 (PA2)
/CC2_RA: R8.1, U5.28 (PB15)
/CC2_RD: R12.1, U5.45 (PB8)
/CC2_RP1A5: R10.1, U5.3 (PC14)
/CC2_RP3A0: R6.1, U5.4 (PC15)
/CC2_RPUSB: R14.1, U5.18 (PB0)
/CC2_TX_DATA: Q3.2 (G), U5.16 (PA6)
/CC2_TX_EN: Q3.5 (G), U5.39 (PB3)
/DAC: U5.14 (PA4)
/LED_B_L: R23.2, U5.27 (PB14)
/LED_G_L: R21.2, U5.22 (PB11)
/LED_R_L: R25.2, U5.26 (PB13)
/NRST: U5.7 (NRST)
/OSC_IN: U5.5 (PF0)
/OSC_OUT: U5.6 (PF1)
/SCL: R22.2, U1.A1 (SCL), U2.A1 (SCL), U5.42 (PB6)
/SDA: R24.2, U1.A2 (SDA), U2.A2 (SDA), U5.43 (PB7)
/TX_CLKIN: NT1.1, U5.15 (PA5)
/TX_CLKOUT: NT1.2, U5.46 (PB9)
/UART_RX: U5.31 (PA10)
/UART_TX: U5.30 (PA9)
/USB_B_D_N: J1.2 (D-), U5.32 (PA11)
/USB_B_D_P: J1.3 (D+), U5.33 (PA12)
/USB_B_ID: J1.4 (ID), Q4.2 (G), R19.2
/USB_B_VBUS: R19.1, R20.1
/USB_C_CC1: J2.A5 (CC1), P1.A5 (CC), Q1.6 (D)
/USB_C_CC2: J2.B5 (CC2), Q1.3 (D), R2.4
/USB_C_CC2_N: R2.2, U2.D2 (VIN_N)
/USB_C_CC2_P: R2.1, U2.D1 (BUS), U2.D3 (VIN_P)
/USB_C_D_N: J2.A7 (D-), J2.B7 (D-), P1.A7 (D-)
/USB_C_D_P: J2.A6 (D+), J2.B6 (D+), P1.A6 (D+)
/USB_C_SBU1: J2.A8 (SBU1), P1.A8 (SBU1)
/USB_C_SBU2: J2.B8 (SBU2), P1.B8 (SBU2)
/USB_C_SSRX1_N: J2.B10 (RX1-), P1.B10 (RX1-)
/USB_C_SSRX1_P: J2.B11 (RX1+), P1.B11 (RX1+)
/USB_C_SSRX2_N: J2.A10 (RX2-), P1.A10 (RX2-)
/USB_C_SSRX2_P: J2.A11 (RX2+), P1.A11 (RX2+)
/USB_C_SSTX1_N: J2.A3 (TX1-), P1.A3 (TX1-)
/USB_C_SSTX1_P: J2.A2 (TX1+), P1.A2 (TX1+)
/USB_C_SSTX2_N: J2.B3 (TX2-), P1.B3 (TX2-)
/USB_C_SSTX2_P: J2.B2 (TX2+), P1.B2 (TX2+)
/USB_C_VBUS_N: R1.1, U1.D2 (VIN_N)
/USB_C_VBUS_P: R1.2, U1.D1 (BUS), U1.D3 (VIN_P)
/VBUS_ALERT_L: U1.A3 (ALERT), U5.20 (PB2)
GND: C1.2, C2.2, C3.2, C4.2, C5.2, C6.2, C7.2, C8.2, D1.2 (A), J1.5 (GND), J1.6 (Shield), J2.A1 (GND), J2.A12 (GND), J2.B1 (GND), J2.B12 (GND), J2.S1 (SHIELD), P1.A1 (GND), P1.A12 (GND), P1.B1 (GND), P1.B12 (GND), P1.S1 (SHIELD), Q2.4 (S), Q3.4 (S), Q4.3 (S), R3.2, R4.2, U1.B3 (A0), U1.C1 (GND), U1.C3 (A1), U2.C1 (GND), U2.C3 (A1), U3.2 (GND), U4.C2, U5.8 (VSSA), U5.23 (VSS), U5.35 (VSS), U5.47 (VSS), U5.49 (VSS)
unnamed: C1.1, FB1.1, U3.3 (EN), U3.4 (IN)
unnamed: C5.1, C6.1, FB2.1, U5.9 (VDDA)
unnamed: D1.1 (K), FB1.2, J1.1 (VBUS)
unnamed: D2.2 (RK), R25.1
unnamed: D2.3 (GK), R23.1
unnamed: D2.4 (BK), R21.1
unnamed: J2.A4 (VBUS), J2.A9 (VBUS), J2.B4 (VBUS), J2.B9 (VBUS), R1.3
unnamed: P1.A4 (VBUS), P1.A9 (VBUS), P1.B4 (VBUS), P1.B9 (VBUS), R1.4
unnamed: P1.B5 (VCONN), R2.3
unnamed: Q1.1 (S), Q2.1 (S), R5.2, R7.2, R9.2, R11.2, R13.2, R16.1, U4.C1 (+)
unnamed: Q1.4 (S), Q3.1 (S), R6.2, R8.2, R10.2, R12.2, R14.2, R18.1, U4.C3 (+)
unnamed: Q2.3 (D), R16.2
unnamed: Q2.6 (D), R15.2
unnamed: Q3.3 (D), R18.2
unnamed: Q3.6 (D), R17.2

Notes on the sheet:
Route as Kelvin Conections
Use OTG + A -to- A Cable to boot
RP resistors to 3v3
ADDR: 0X41
ADDR: 0X40

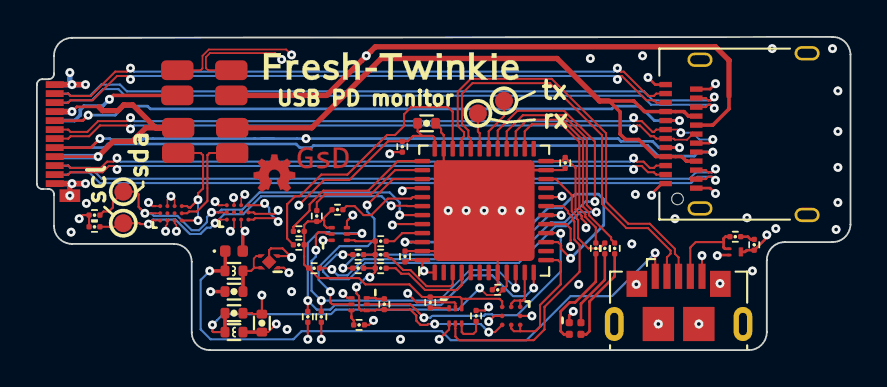
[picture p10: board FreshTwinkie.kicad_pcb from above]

Board: 4 copper layers, 45.2 x 17.4 mm, 50 parts (1 on the bottom side), 67 nets.

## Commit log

2021-01-21 Add FreshTwinkie v0.1 hardware files
    [FreshTwinkie.csv, FreshTwinkie.kicad_pcb, FreshTwinkie.sch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]
2023-06-09 Add 3d printable case
    [lower-case.stl, upper-case.stl]
